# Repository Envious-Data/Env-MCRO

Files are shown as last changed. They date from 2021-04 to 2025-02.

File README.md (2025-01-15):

# Env-MCRO
 A Raspberry Pi Pico powered Macro board, like a Streamdeck but cheaper and simpler.

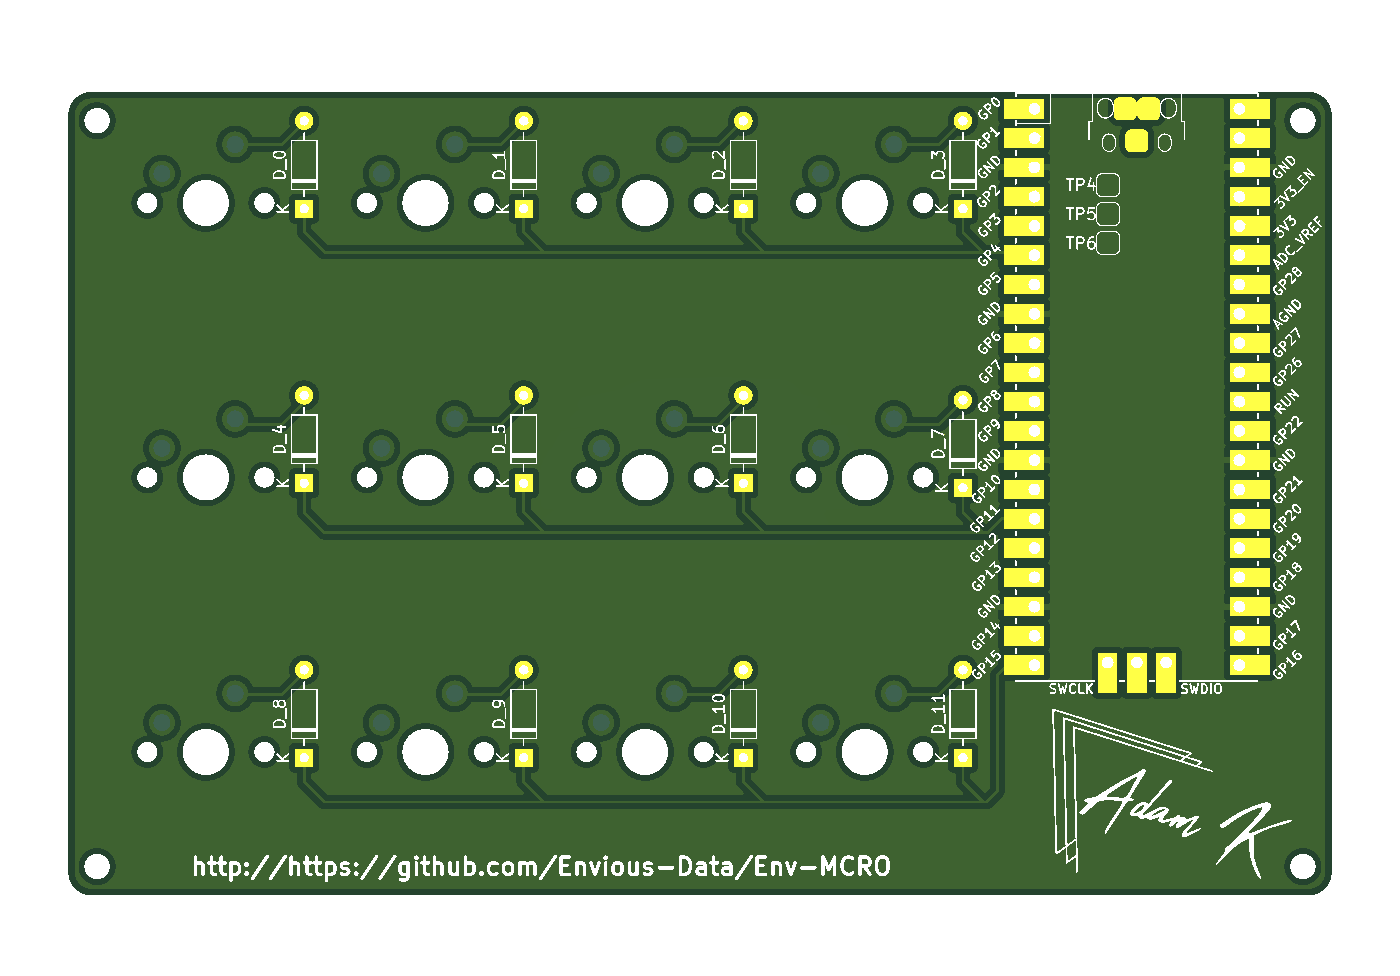
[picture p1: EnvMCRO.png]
Board Image

(btw this image is a bit outdated, some of the silkscreen has changed but its physically the same)

### What This?
This is another another mechanical keyboard type thing, this is a small 12 key macro board intended to be used for F13 to F24 but you can do whatever.
I do feel like the rpi pico is a bit overkill for this use, a tiny2040 will probably fit better, Ill have to see if someone has made kidcad bits for that if not Ill probably have to make them my self or whatever.

### Parts List
* 1x Raspberry Pi Pico
* 12x Keyboard Switches
* 12x 1N4148 Diodes (through hole)
* 12x Keycaps
* 1x Rotary Encoder (optional)
* 12X SK6812 Mini-e LEDs (optional)
* Macro Board PCB
- (The board dimentions are: 109.6mm x 69.7mm)

### Quick setup guide
* Connect the Raspberry pi pico to your PC holding the Bootsel button
  * a USB Drive should show up called RP2-BOOT
* Download [This](blob:https://github.com/d1d8b8da-7e8d-4b2f-9aaf-276d6753a1cd) File and copy it to the drive called RP2-BOOT

the board should reboot and startup with the default keymap, you are good to use it however you wish but if you wish to re-map the board you can look at the QMK code and modify it as you see fit.

By default the macro board is mapped with keys F13 to F24 but you can go [Here](https://github.com/KMKfw/kmk_firmware/blob/master/docs/en/keycodes.md) and look at what keys you can re-map with.

not all software supports the F13 to F24 keys but a couple of examples that do are OBS and BeamNG.Drive

### QMK
Ive built QMK for these boards, if you want to remap it be sure to use the VIA version of the MCRO firmware, download the respective via JSON from the folder and sideload it in via.
https://github.com/Envious-Data/EnvKB-QMK/tree/main/_PREBUILTFIRMWARES

### extra bits!
User TonyPJ on Thingiverse has made a small 3d printable stand: https://www.thingiverse.com/thing:4896875

Project was Selected for Booster Conf as part of a Mechanical Keyboards Talk, a 3d printable case was made and can be found here: https://github.com/vidarw/booster-2025-macroboard

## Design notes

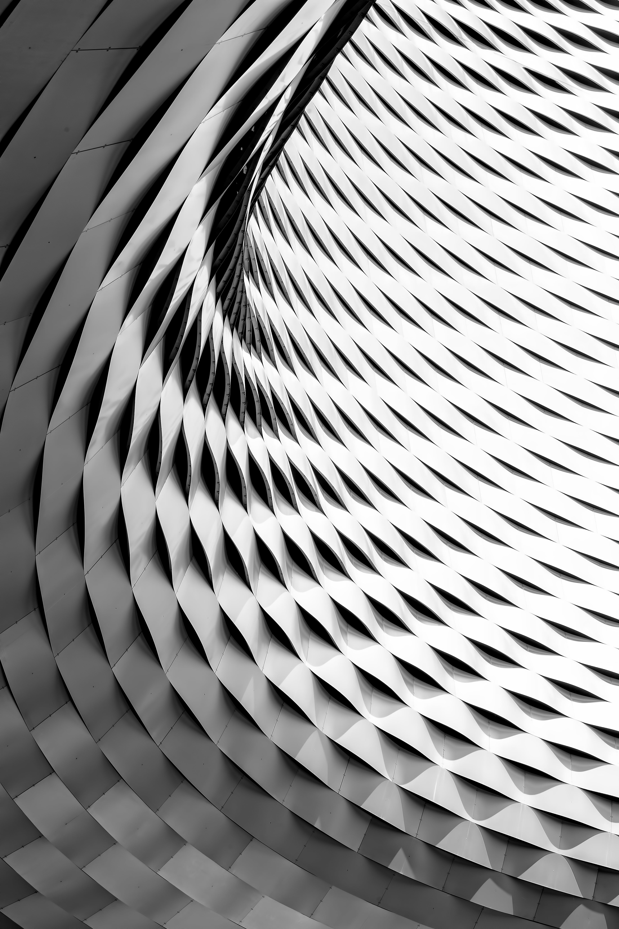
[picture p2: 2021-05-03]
_miscellaneous/gfx1.jpg

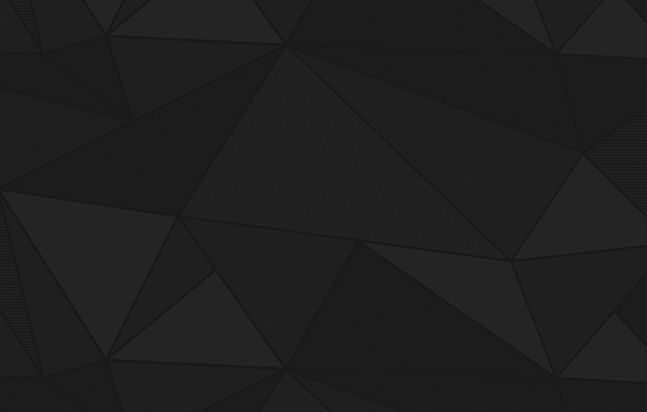
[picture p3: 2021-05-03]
_miscellaneous/gfx2.jpg

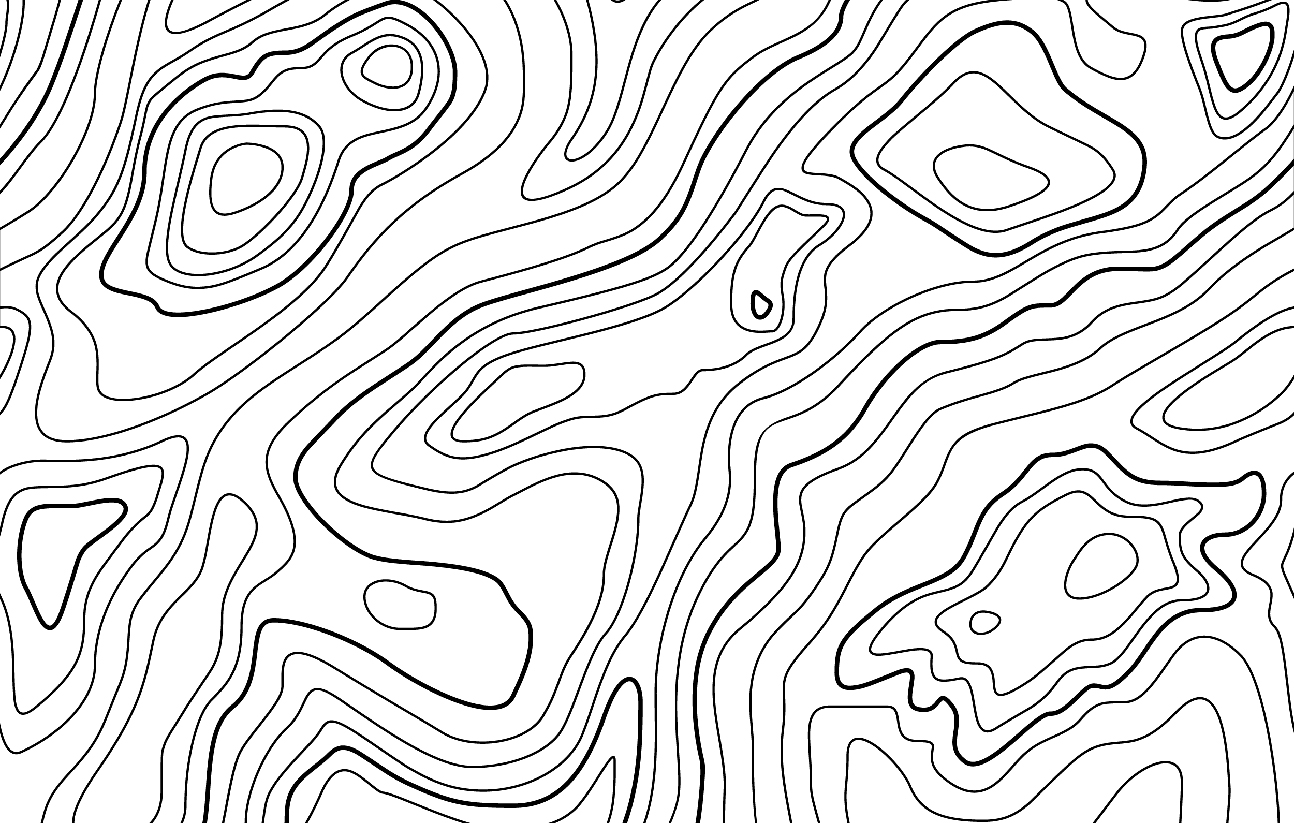
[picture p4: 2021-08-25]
_miscellaneous/gfx3.jpg

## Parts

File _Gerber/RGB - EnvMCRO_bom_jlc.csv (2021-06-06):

Comment | Designator | Footprint | LCSC Part #
SK6812MINI-E | D1,D2,D3,D4,D5,D6,D7,D8,D9,D10,D11,D12 | MX_SK6812MINI-E_REV | no_part_number
D | D_11,D_10,D_9,D_8,D_7,D_6,D_5,D_4,D_3,D_2,D_1,D_0 | D_DO-35_SOD27_P7.62mm_Horizontal | no_part_number
MountingHole | H1,H2,H3,H4 | MountingHole_2.2mm_M2 | no_part_number
KEYSW | K_11,K_10,K_9,K_8,K_7,K_6,K_5,K_4,K_3,K_2,K_1,K_0 | MXOnly-1U-NoLED | no_part_number
Pico | U1 | RPi_Pico_SMD_TH | no_part_number

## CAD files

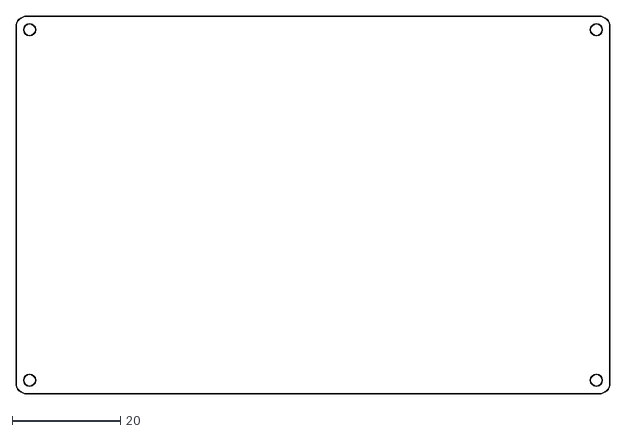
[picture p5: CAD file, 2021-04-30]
_Gerber/EnvMCRO-BackAcrylic.dxf
109.6 x 69.7

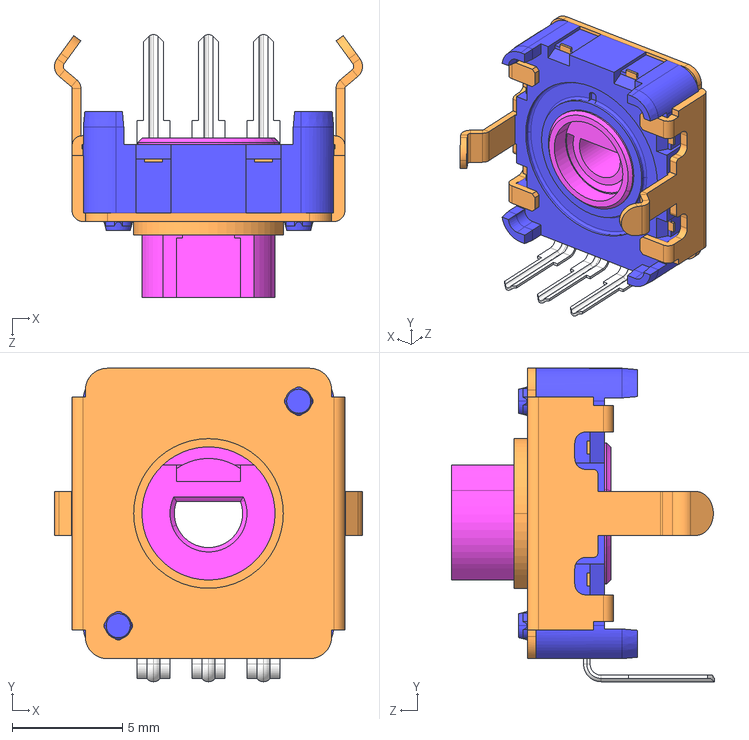
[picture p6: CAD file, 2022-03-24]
_miscellaneous/EC12E-085.step
14.0 x 14.3 x 11.9 mm

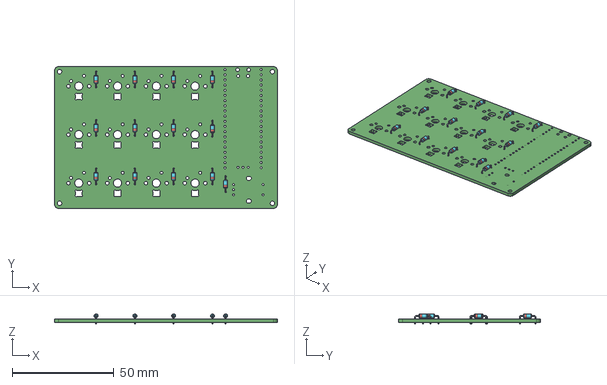
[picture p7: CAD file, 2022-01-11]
MainPCB_RPI-PICO/EnvMCRO.step
109.6 x 69.7 x 5.01 mm

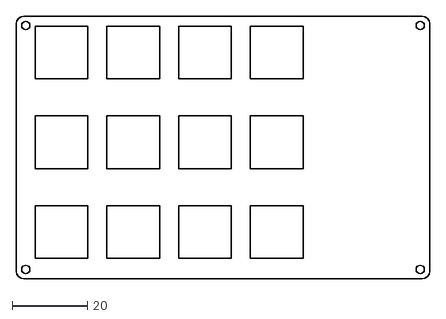
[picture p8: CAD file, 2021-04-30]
_Gerber/EnvMCRO-FrontAcrylic.dxf
109.6 x 69.7

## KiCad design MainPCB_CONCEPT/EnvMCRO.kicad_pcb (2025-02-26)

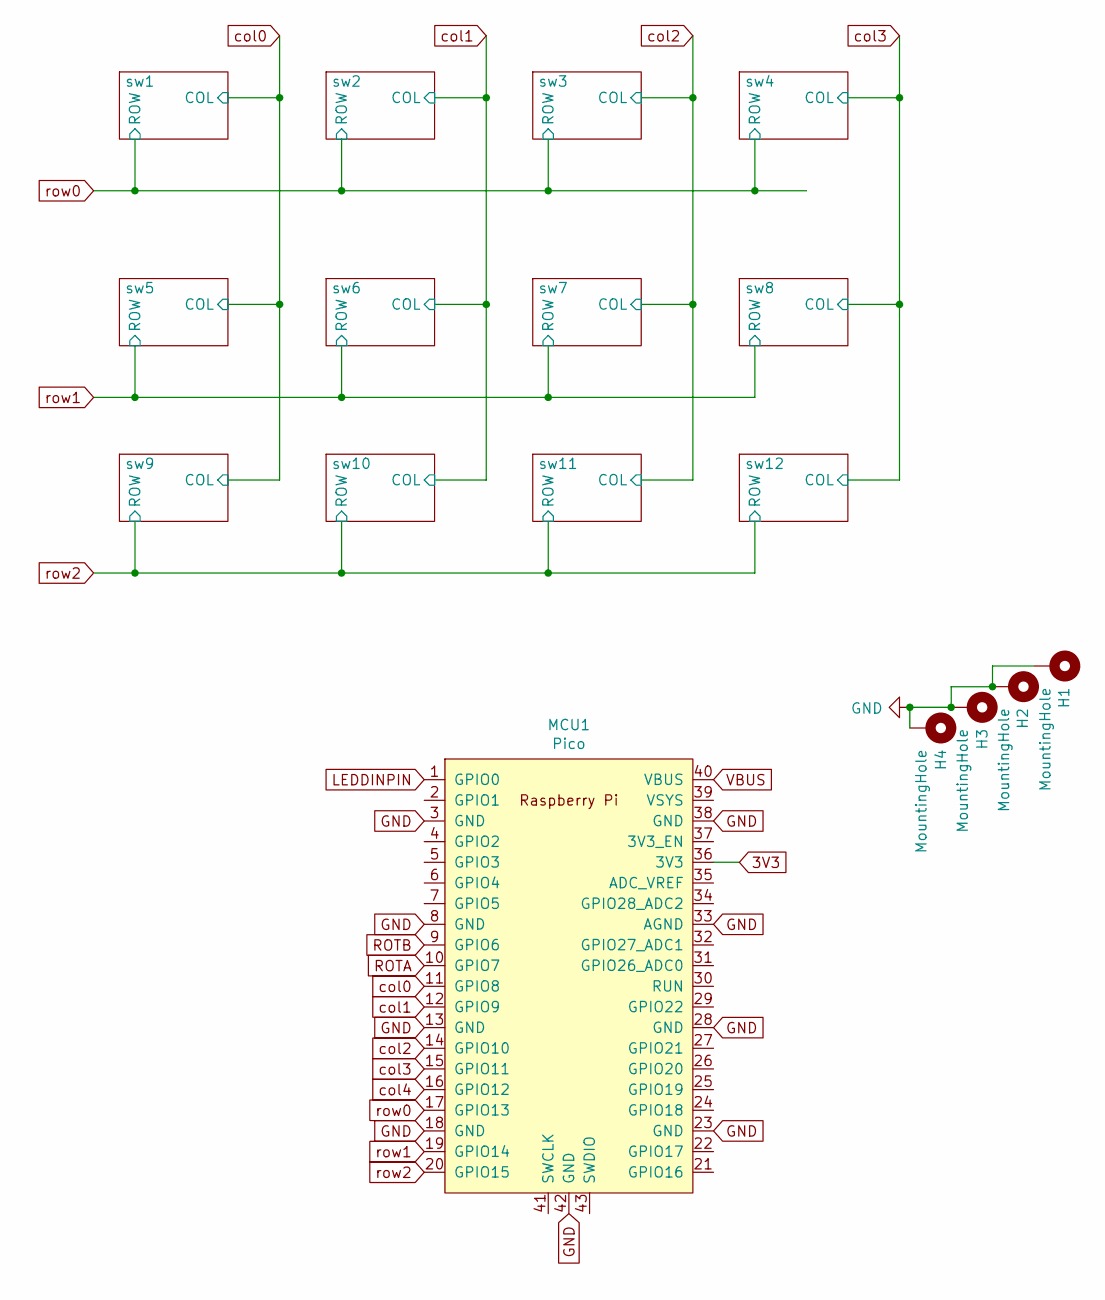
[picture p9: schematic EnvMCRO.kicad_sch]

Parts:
H1, H2, H3, H4: MountingHole; MountingHole_2.2mm_M2_Pad
MCU1: Pico; RPi_Pico_SMD_TH

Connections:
3V3: MCU1.36 (3V3); also elsewhere on the board
GND: H1.1, H2.1, H3.1, H4.1, MCU1.3 (GND), MCU1.8 (GND), MCU1.13 (GND), MCU1.18 (GND), MCU1.23 (GND), MCU1.28 (GND), MCU1.33 (AGND), MCU1.38 (GND), MCU1.42 (GND); also elsewhere on the board
LEDDINPIN: MCU1.1 (GPIO0)
ROTA: MCU1.10 (GPIO7)
ROTB: MCU1.9 (GPIO6)
VBUS: MCU1.40 (VBUS)
col0: MCU1.11 (GPIO8); also elsewhere on the board
col1: MCU1.12 (GPIO9); also elsewhere on the board
col2: MCU1.14 (GPIO10); also elsewhere on the board
col3: MCU1.15 (GPIO11); also elsewhere on the board
col4: MCU1.16 (GPIO12)
row0: MCU1.17 (GPIO13); also elsewhere on the board
row1: MCU1.19 (GPIO14); also elsewhere on the board
row2: MCU1.20 (GPIO15); also elsewhere on the board

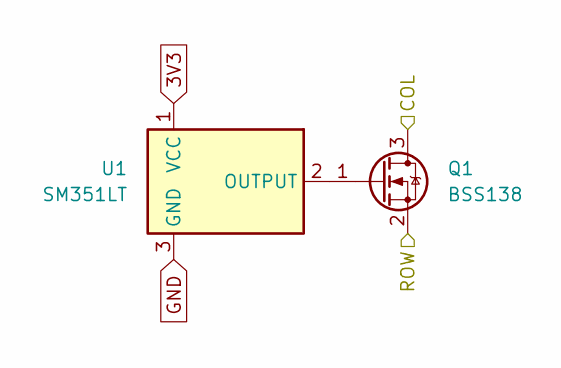
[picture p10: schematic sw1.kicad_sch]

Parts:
Q1: BSS138; SOT-23
U1: SM351LT; SOT-23

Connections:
3V3: U1.1 (VCC); also elsewhere on the board
GND: U1.3 (GND); also elsewhere on the board
unnamed: Q1.1 (G), U1.2 (OUTPUT)
col0: Q1.3 (D); also elsewhere on the board
row0: Q1.2 (S); also elsewhere on the board

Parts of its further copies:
Q2, Q3, Q4, Q5, Q6, Q7, Q8, Q9, Q10, Q11, Q12: BSS138; SOT-23
U2, U3, U4, U5, U6, U7, U8, U9, U10, U11, U12: SM351LT; SOT-23

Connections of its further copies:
3V3: U2.1 (VCC), U3.1 (VCC), U4.1 (VCC), U5.1 (VCC), U6.1 (VCC), U7.1 (VCC), U8.1 (VCC), U9.1 (VCC), U10.1 (VCC), U11.1 (VCC), U12.1 (VCC); also elsewhere on the board
GND: U2.3 (GND), U3.3 (GND), U4.3 (GND), U5.3 (GND), U6.3 (GND), U7.3 (GND), U8.3 (GND), U9.3 (GND), U10.3 (GND), U11.3 (GND), U12.3 (GND); also elsewhere on the board
unnamed: Q2.1 (G), U2.2 (OUTPUT)
unnamed: Q3.1 (G), U3.2 (OUTPUT)
unnamed: Q4.1 (G), U4.2 (OUTPUT)
unnamed: Q5.1 (G), U5.2 (OUTPUT)
unnamed: Q6.1 (G), U6.2 (OUTPUT)
unnamed: Q7.1 (G), U7.2 (OUTPUT)
unnamed: Q8.1 (G), U8.2 (OUTPUT)
unnamed: Q9.1 (G), U9.2 (OUTPUT)
unnamed: Q10.1 (G), U10.2 (OUTPUT)
unnamed: Q11.1 (G), U11.2 (OUTPUT)
unnamed: Q12.1 (G), U12.2 (OUTPUT)
col0: Q5.3 (D), Q9.3 (D); also elsewhere on the board
col1: Q2.3 (D), Q6.3 (D), Q10.3 (D); also elsewhere on the board
col2: Q3.3 (D), Q7.3 (D), Q11.3 (D); also elsewhere on the board
col3: Q4.3 (D), Q8.3 (D), Q12.3 (D); also elsewhere on the board
row0: Q2.2 (S), Q3.2 (S), Q4.2 (S); also elsewhere on the board
row1: Q5.2 (S), Q6.2 (S), Q7.2 (S), Q8.2 (S); also elsewhere on the board
row2: Q9.2 (S), Q10.2 (S), Q11.2 (S), Q12.2 (S); also elsewhere on the board

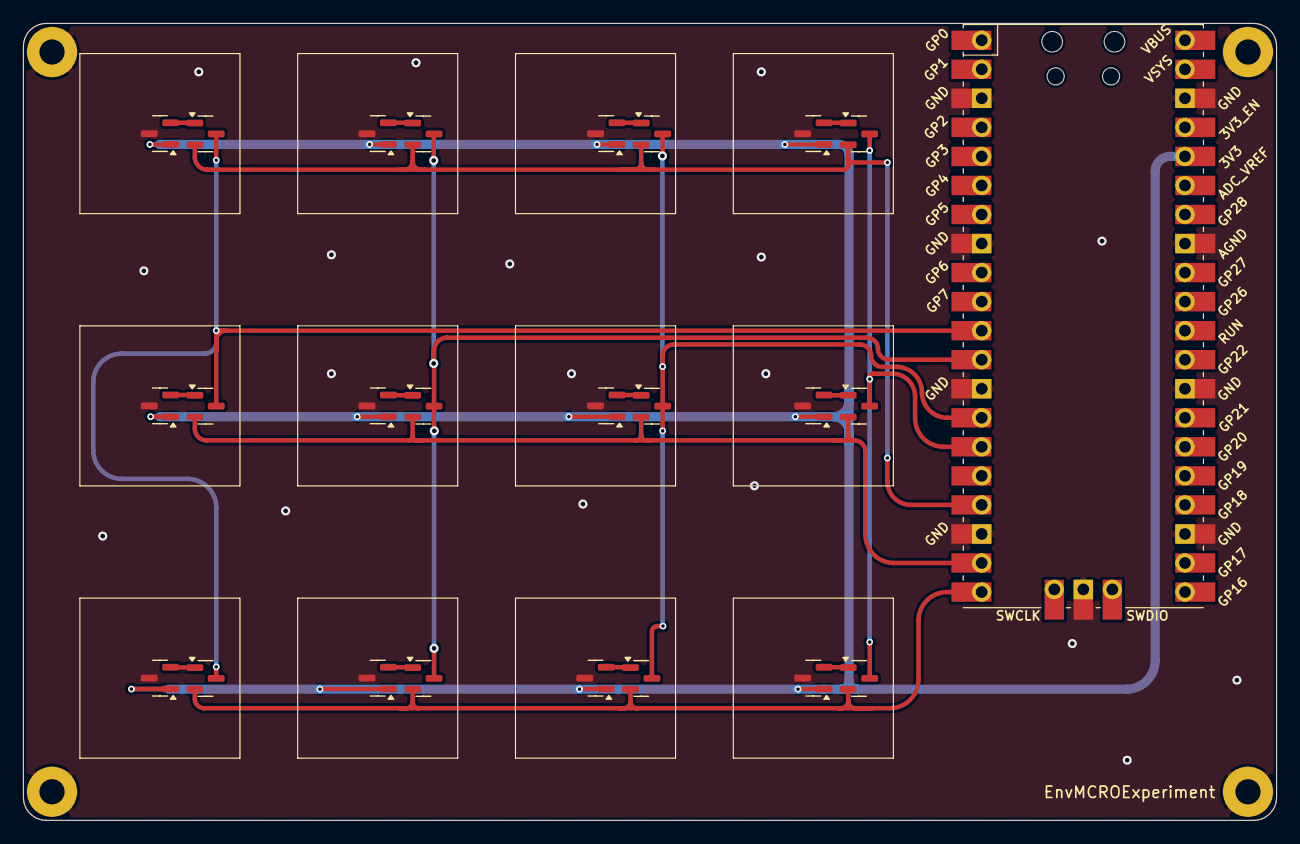
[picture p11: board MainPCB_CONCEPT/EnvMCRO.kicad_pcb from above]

Board: 2 copper layers, 109.6 x 69.7 mm, 29 parts (0 on the bottom side), 21 nets.

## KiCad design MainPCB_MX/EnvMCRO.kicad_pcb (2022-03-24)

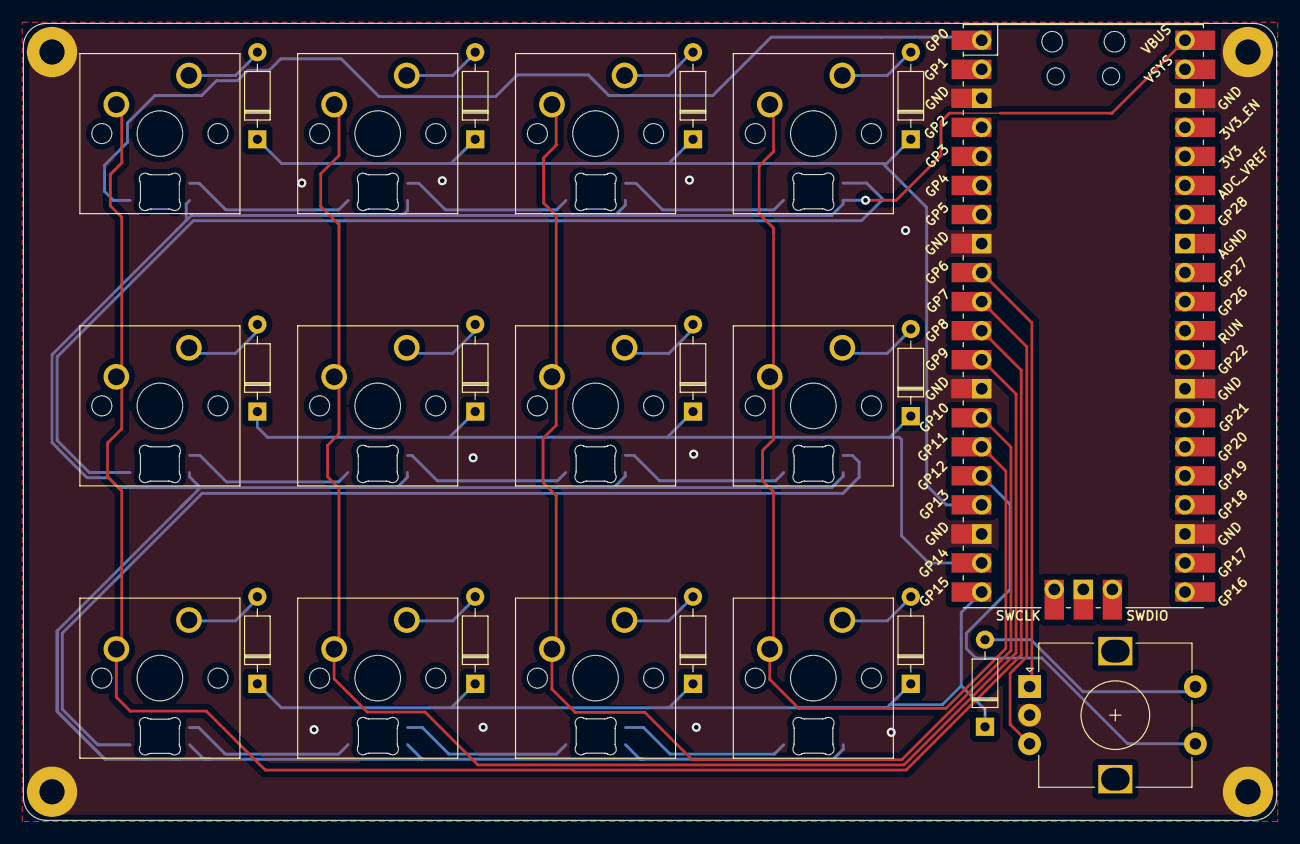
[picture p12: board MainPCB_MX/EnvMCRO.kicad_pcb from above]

Board: 2 copper layers, 109.6 x 69.7 mm, 43 parts (0 on the bottom side), 37 nets.

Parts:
D1, D2, D3, D4, D5, D6, D7, D8, D9, D10, D11, D12: SK6812MINI-E; MX_SK6812MINI-E_REV
D_0, D_1, D_2, D_3, D_4, D_5, D_6, D_7, D_8, D_9, D_10, D_11, D_14: D; D_DO-35_SOD27_P7.62mm_Horizontal
H1, H2, H3, H4: MountingHole; MountingHole_2.2mm_M2_Pad
K_0, K_1, K_2, K_3, K_4, K_5, K_6, K_7, K_8, K_9, K_10, K_11: KEYSW; MXOnly-1U-NoLED
SW1: Rotary_Encoder_Switch; RotaryEncoder_Alps_EC12E-Switch_Vertical_H20mm
U1: Pico; RPi_Pico_SMD_TH

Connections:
GND: D1.3, D2.3, D3.3, D4.3, D5.3, D6.3, D7.3, D8.3, D9.3, D10.3, D11.3, D12.3, H1.1, H2.1, H3.1, H4.1, SW1.C, U1.3, U1.8, U1.13, U1.18, U1.23, U1.28, U1.38
LEDDINPIN: D1.4, U1.1
unnamed: D1.2, D2.4
unnamed: D2.2, D3.4
unnamed: D3.2, D4.4
unnamed: D4.2, D5.4
unnamed: D5.2, D6.4
unnamed: D6.2, D7.4
unnamed: D7.2, D8.4
unnamed: D8.2, D9.4
unnamed: D10.2, D11.4
unnamed: D9.2, D10.4
unnamed: D11.2, D12.4
unnamed: D_0.2, K_0.2
unnamed: D_1.2, K_1.2
unnamed: D_2.2, K_2.2
unnamed: D_3.2, K_3.2
unnamed: D_4.2, K_4.2
unnamed: D_5.2, K_5.2
unnamed: D_6.2, K_6.2
unnamed: D_7.2, K_7.2
unnamed: D_8.2, K_8.2
unnamed: D_9.2, K_9.2
unnamed: D_10.2, K_10.2
unnamed: D_11.2, K_11.2
unnamed: D_14.2, SW1.S1
ROTA: SW1.B, U1.10
ROTB: SW1.A, U1.9
VBUS: D1.1, D2.1, D3.1, D4.1, D5.1, D6.1, D7.1, D8.1, D9.1, D10.1, D11.1, D12.1, U1.40
col0: K_0.1, K_4.1, K_8.1, U1.11
col1: K_1.1, K_5.1, K_9.1, U1.12
col2: K_2.1, K_6.1, K_10.1, U1.14
col3: K_3.1, K_7.1, K_11.1, U1.15
col4: SW1.S2, U1.16
row0: D_0.1, D_1.1, D_2.1, D_3.1, U1.17
row1: D_4.1, D_5.1, D_6.1, D_7.1, U1.19
row2: D_8.1, D_9.1, D_10.1, D_11.1, D_14.1, U1.20

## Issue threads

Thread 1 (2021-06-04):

RGB keys

jonfitt, 2021-06-04:
Do you think there's room for one of these on the board?
[https://www.adafruit.com/product/453](https://www.adafruit.com/product/453)

You can address 64 LEDs (enough for 12 keys * 3 RGB) using 4 pins on the Pico as an SPI interface.

I'm sure there's an SPI library already out there.

Maybe if there was a revision using a smaller board than the Pico?

Envious-Data, 2021-06-04:
there are enough spare pins on the Raspberry pi pico, I think a better solution would be to run traces for SK6812 LEDs since you can address all of them on this board using just 3 pins and 2 of which are +5V and GND.

Envious-Data, 2021-06-04:
Update:

Added Pads and traces for RGB LEDs, the pads fit 3535 SK6812 or WS2812**B** and also generated a gerber for LED version
in KMK you need to modify rgb.py with the right information (board.GP5 is the data pin for the LEDs)

if you order via JLCPCB you'll have to select WS2812B 3535 LEDs as they do not stock SK6812s

its also important to make sure you have the B varient of WS2812

Enjoy 👍

Closed 2021-06-15.

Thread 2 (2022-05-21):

PICO shuts down on key stroke.

xfatdannx, 2022-05-21:
I am not sure if this is an error in the script or a hardware error but the PICO seems to shut down (green LED turns off) upon first key stroke. It will stay on non-stop if no key is pressed. Have you seen this issue before?

Envious-Data, 2022-05-21:
do you have Circuitpython 7.2.5 installed?

xfatdannx, 2022-05-22:
Yes, everything has been installed and in working order for some time. After a resent tear down of my PC, it may have gone unused for 3-4 weeks max. Do you think it may just need to be re-flashed?

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

Envious-Data, 2022-05-28:
Might be worth a try, I havent personally experienced that.

Closed 2022-08-06.

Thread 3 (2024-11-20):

built a board but it doesn't respond to key presses

KayleaS, 2024-11-20:
parts used are as follows

https://www.amazon.ca/dp/B0C6FH6XQ7?ref=ppx_yo2ov_dt_b_fed_asin_title (key switches)

https://www.amazon.ca/dp/B09KVB8LVR?ref=ppx_yo2ov_dt_b_fed_asin_title (Pi Pico)

https://www.digikey.ca/en/products/detail/onsemi/1N4148/458603 (diodes) based on what is in readme

wondering if it's maybe my diodes, or if i'm doing something wrong, can provide more info if needed

Envious-Data, 2024-11-20:
I take it you ordered the PCBs from inside the _gerber folder?

KayleaS, 2024-11-20:
Yes

KayleaS, 2024-11-20:
it seems i ordered the rgb version and i have no leds or the rotary encoder fitted, would that stop it from working

Envious-Data, 2024-11-21:
Nah those shouldnt be an issue

Ive updated the QMK firmware build, the default buttons are mapped to F13 to F24 so by default they wont do anything unless you specifically map software or game buttons to them

lemme know if all is good once you flash this.
https://github.com/Envious-Data/EnvKB-QMK/blob/main/_PREBUILTFIRMWARES/enviousdesign_mcro_rev2_default.uf2

KayleaS, 2024-11-22:
yes it works, thanks for all the help

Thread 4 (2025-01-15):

3D Printable case for Env-MCRO

vidarw, 2025-01-15:
Hi,
As part of this years Booster Conf (https://www.boosterconf.no/2025/talks/) me and two friends will be holding a workshop about Mechanical Keyboards and the DYI culture where people get to build their first mechanical keyboard device.

We chose the Env-MCRO board for this as the design is simple to solder and parts list is affordable. We have designed a case for this so it will be ready to use, and it will also double as a platform for us to promote the logos of our parts sponsors.

It would be cool if you added a link to the repository: https://github.com/vidarw/booster-2025-macroboard
It is still WIP but everything will be in place in the common weeks - including build instructions.

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

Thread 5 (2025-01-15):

Issues with VIA Firmware and usevia.app

vidarw, 2025-01-15:
Gerber the RGB version which I assume is the v2.0 version.

Keyboard works and Is as documented mapped to the higher level F-keys when for example reading key events with JavaScript.
When loading the usevia.app interface device shows up.

I have loaded the v2.0 json and set the spec to v2.0 but the app gives the following error logs:

```
17:51:44.135
Fetching v3 definition failed
Device: MCRO 2.0
Vid: 0x2345
Pid: 0x0548

17:51:56.400
InvalidStateError: The device must be opened first.
at HID.write (https://usevia.app/assets/index-12385403.js:1:11124)
at async KeyboardAPI._hidCommand (https://usevia.app/assets/index-12385403.js:3:9013)
at async KeyboardAPI.flushQueue (https://usevia.app/assets/index-12385403.js:3:8661)
Device: MCRO 2.0

Vid: 0x2345
Pid: 0x0548
17:51:56.402
Received invalid protocol version from device
Device: MCRO 2.0
Vid: 0x2345
Pid: 0x0548
```

Any thoughts? Would be nice to be able to use the Via software to remap keys, etc.

vidarw, 2025-01-16:
My board (without rotary and LEDs) works as expected with this fix.

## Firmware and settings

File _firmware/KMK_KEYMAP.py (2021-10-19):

#PiPi-GHERKIN - Raspberry Pi PICO
#Rpi pico keyboard keymap, I used the gherkin keymap as a example :)
print("Starting")

#run the led
import board
import pwmio
import time

led = pwmio.PWMOut(board.GP25, frequency=60, duty_cycle=1024, variable_frequency=True)

import board
from kmk.kmk_keyboard import KMKKeyboard
from kmk.keys import KC
from kmk.matrix import DiodeOrientation
from kmk.modules.layers import Layers
from kmk.keys import KC, make_key
envkb = KMKKeyboard()

envkb.col_pins = (board.GP18, board.GP19, board.GP20, board.GP21)
envkb.row_pins = (board.GP4, board.GP11, board.GP15)
envkb.diode_orientation = DiodeOrientation.COLUMNS

rollover_cols_every_rows = 4
envkb.diode_orientation = DiodeOrientation.COLUMNS
envkb.debug_enabled = False

layers = Layers()
envkb.modules = [layers]

nokey = KC.NO
envkb.keymap = [
    [
        KC.F13, KC.F14, KC.F15, KC.F16,
        KC.F17, KC.F18, KC.F19, KC.F20,
        KC.F21, KC.F22, KC.F23, KC.F24,
    ],
]

def usbfunc():
    
    if __name__ == '__main__':
        led.duty_cycle=16384
        envkb.go()
        raise Exception('Something has caused an error.')
        
try:
    usbfunc()
except KeyboardInterrupt:
    led.duty_cycle=0
except Exception as e:
    print(e)
    led.duty_cycle=0

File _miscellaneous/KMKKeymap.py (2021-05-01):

#PiPi-GHERKIN - Raspberry Pi PICO
#Rpi pico keyboard keymap, I used the gherkin keymap as a example :)
import board
from kmk.keys import KC
from kmk.kmk_keyboard import KMKKeyboard
from kmk.matrix import DiodeOrientation
from kmk.hid import HIDModes

envkb = KMKKeyboard()
envkb.col_pins = (board.GP18, board.GP19, board.GP20, board.GP21)
envkb.row_pins = (board.GP4, board.GP11, board.GP15)
envkb.diode_orientation = DiodeOrientation.COLUMNS
envkb.debug_enabled = False
nokey = KC.NO
envkb.keymap = [
    [
        KC.F13, KC.F14, KC.F15, KC.F16,
        KC.F17, KC.F18, KC.F19, KC.F20,
        KC.F21, KC.F22, KC.F23, KC.F24,
    ],
]

#Simple thing to enable LED on pi once this script is executed
import board
import digitalio
led = digitalio.DigitalInOut(board.GP25)
led.direction = digitalio.Direction.OUTPUT
led.value = True
#At this point once the LED is enabled the keyboard should be usable
#I'm not entirely sure why it takes so long since I have no idea how KMK works and I havent exactly looked into KMKs code much
#This might be a problem if you are trying to get into the bios of your PC
if __name__ == '__main__':
    envkb.go(hid_type=HIDModes.USB) #Wired USB enables

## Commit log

2021-04-11 Removed unused pads, Added modified footprint of rpi pico
    [EnvMCRO.kicad_pcb]
2021-04-11 Added lines for plate and backing.
    [EnvMCRO.kicad_pcb]
2021-04-11 Added some Gerber bits and SVGs for laser cutting
    [EnvMCRO-B_Cu.gbr, EnvMCRO-B_Mask.gbr, EnvMCRO-B_Paste.gbr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]
2021-04-17 Some Mechanical CAD Work.
    [EnvMCRO-B_Cu.gbr, EnvMCRO-B_Mask.gbr, EnvMCRO-B_Paste.gbr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]
2021-04-21 Updated Laser Cut SVGs
    [EnvMCRO.kicad_pcb]
2021-04-30 Correct Laser cut DXF
    This change needs to be un-done every time you generate a gerber
    [EnvMCRO-BackAcrylic.dxf, EnvMCRO-FrontAcrylic.dxf, EnvMCRO.kicad_pcb]
2021-05-02 Fixed the error in the silkscreen
    "http://https://" idk how I missed this
    [EnvMCRO-B_Cu.gbr, EnvMCRO-B_Mask.gbr, EnvMCRO-B_Paste.gbr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]
2021-05-02 Updated Gerber bits with new graphics design
    and also correct format!
    [EnvMCRO-B_Cu.gbl, EnvMCRO-B_Mask.gbs, EnvMCRO-B_Paste.gbp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]
2021-05-03 Updated graphics design on board
    added the github URL back but now its shiny!
    [EnvMCRO-B_Cu.gbl, EnvMCRO-B_Mask.gbs, EnvMCRO-B_Paste.gbp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]
2021-05-03 Additional silkscreen design
    [EnvMCRO-B_Cu.gbl, EnvMCRO-B_Mask.gbs, EnvMCRO-B_Paste.gbp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]
2021-05-08 Added a gerber for plain pcb w/ no graphics
    [EnvMCRO-B_Cu.gbl, EnvMCRO-B_Mask.gbs, EnvMCRO-B_Paste.gbp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]
2021-05-26 Cleaned up repo, created backing PCB.
    [EnvMCRO-B_Cu.gbl, EnvMCRO-B_Mask.gbs, EnvMCRO-B_Paste.gbp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]
2021-05-27 Added Mechboards logo for later use
    [EnvMCRO-B_Cu.gbl, EnvMCRO-B_Mask.gbs, EnvMCRO-B_Paste.gbp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]
2021-05-27 Added logo to back plate
    [EnvMCRO-B_Cu.gbl, EnvMCRO-B_Mask.gbs, EnvMCRO-B_Paste.gbp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]
2021-05-31 Renamed Gerber files so they are easier to work with in large orders
2021-06-04 Added Pads/traces for 3535 SK6812 or WS2812B
    [EnvMCRO-B_Cu.gbl, EnvMCRO-B_Mask.gbs, EnvMCRO-B_Paste.gbp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]
2021-06-05 smol aesthetic tweak
    [EnvMCRO.kicad_pcb]
2021-06-06 better RGB implementation using SK6812 MINI E footprints to be installed reverse on the back of the PCB + generated gerber
    [EnvMCRO-B_Cu.gbl, EnvMCRO-B_Mask.gbs, EnvMCRO-B_Paste.gbp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]
2021-08-25 testing new graphic for the board.
    [EnvMCRO.kicad_pcb]
2021-09-04 organized stuff a bit, added rotary encoder, added pro micro version with 2 rotary encoders.
    [EnvMCRO-B_Cu.gbl, EnvMCRO-B_Mask.gbs, EnvMCRO-B_Paste.gbp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]
2021-09-05 updated macro boards to have padded mount holes and github url
    [EnvMCRO.kicad_pcb, EnvMCRO.sch]
2021-09-05 swapped EC11 for EC12 because cheaper, might swap again to what ever people get a hold of the easiest.
    [EnvMCRO.kicad_pcb, EnvMCRO.sch]
2021-09-13 created a version with both a pro micro and a pico footprint
    [CUI_SJ-43614-SMT-TR.step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]
2021-11-20 small fix for the CPL
    [RGB - EnvMCRO_cpl_jlc.csv]
2021-11-22 fixed pads and generated updated gerber
    [EnvMCRO-B_Cu.gbl, EnvMCRO-B_Mask.gbs, EnvMCRO-B_Paste.gbp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]
2022-01-11 exported model to design a case around (tempoary)
    [EnvMCRO-Edge_Cuts.dxf, EnvMCRO.kicad_pcb, EnvMCRO.step]
2022-03-24 some updates and got rid of other versions, plan to make a XL version in the future that will stay.
    [CUI_SJ-43614-SMT-TR.step, EC12E-085.step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]
2023-01-20 renamed main version to make more sense in the future and created a MX ULP version
    [EnvMCRO-Edge_Cuts.dxf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]
2023-01-20 update gitignore
    [EnvMCRO.kicad_pcb]
2025-02-26 made experimental magnet wand board.
    [EnvMCRO.kicad_pcb, EnvMCRO.kicad_sch, sw1.kicad_sch]
